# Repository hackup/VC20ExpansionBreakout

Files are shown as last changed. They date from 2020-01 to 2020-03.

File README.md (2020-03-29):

# Commodore VC20/VIC20 Cartridge Port Breakout

This is an adapter board for the [cartridge port](https://en.wikipedia.org/wiki/Commodore_VIC-20#Ports_and_sockets) of the Commodore VIC20 aka. VC20. It connects the cartridge port to a standard 830 pin prototyping breadboard to assist with the development of modules or cartridges.

Additionally, it features an optional on-board slot for either a 27c512 or 27c020 EPROM. The data bus lines D0-D7 and the address bus lines A0-A12 are connected directly to the slot, as are GND and the 5V power rail. The remaining address bus lines of the EPROM and CE/OE are available on J4. Jumper JP1 must be closed if a 27c512 chip is used.

**USE AT YOUR OWN RISK!**

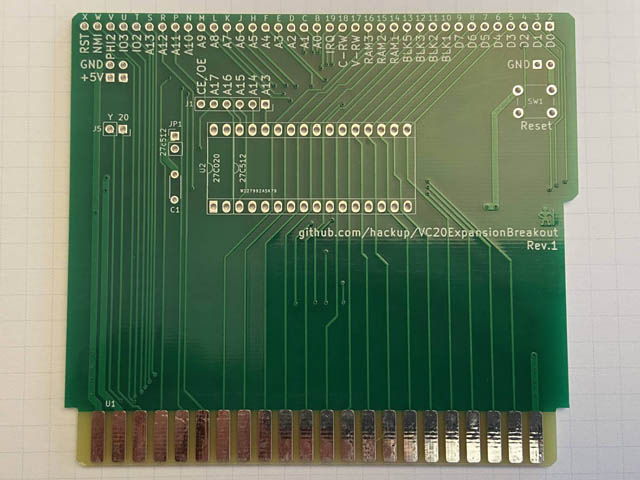
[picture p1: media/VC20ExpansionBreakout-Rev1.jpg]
VC20ExpansionBreakout Rev. 1


This adapter was modelled after my similar [breakout-board for the C64](https://github.com/hackup/C64ExpansionBreakout).

## License


This work is licensed under a
[Creative Commons Attribution-NonCommercial-ShareAlike 4.0 International License](http://creativecommons.org/licenses/by-nc-sa/4.0/).

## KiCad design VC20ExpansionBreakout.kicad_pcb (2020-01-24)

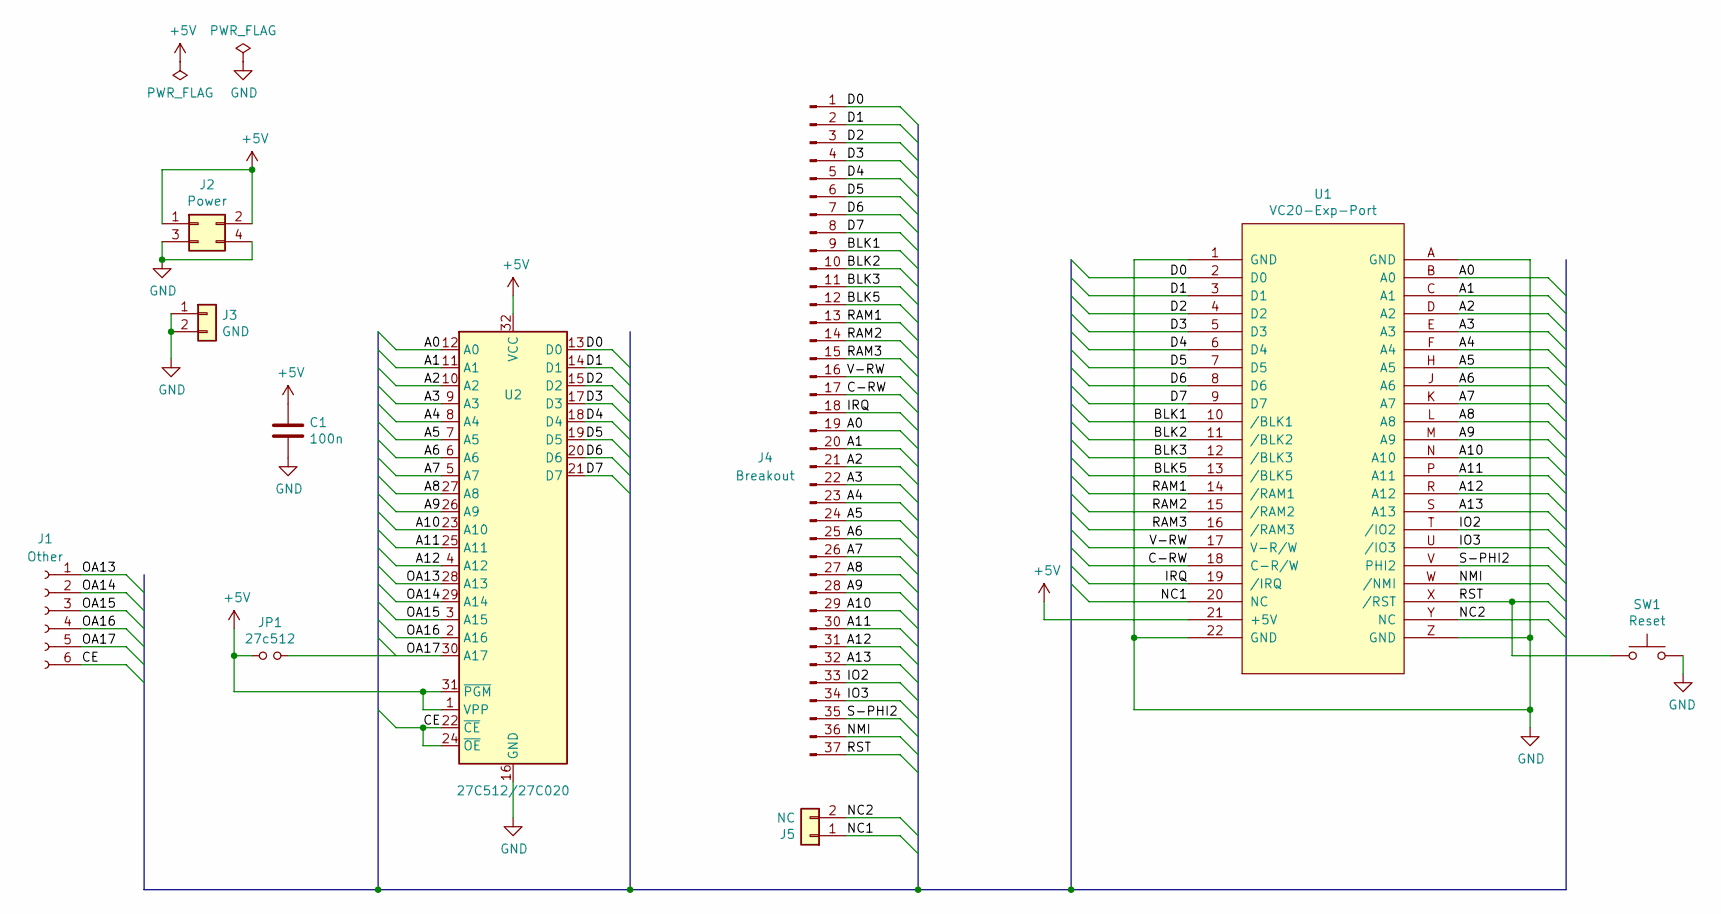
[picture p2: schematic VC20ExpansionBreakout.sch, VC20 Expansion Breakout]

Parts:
C1: 100n; C_Disc_D4.3mm_W1.9mm_P5.00mm
J1: Other; PinSocket_1x06_P2.54mm_Vertical
J2: Power; PinHeader_2x02_P2.54mm_Vertical
J3: GND; PinHeader_1x02_P2.54mm_Vertical
J4: Breakout; PinHeader_1x37_P2.54mm_Vertical
J5: NC; PinSocket_1x02_P2.54mm_Vertical
JP1: 27c512; PinHeader_1x02_P2.54mm_Vertical
SW1: Reset; SW_PUSH_6mm
U1: VC20-Exp-Port; VC20-Cart
U2: 27C512/27C020; DIP-32_W15.24mm_Socket_LongPads

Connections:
+5V: C1.1, J2.1, J2.2, JP1.1, U1.21 (+5V), U2.1 (VPP), U2.31 (~PGM), U2.32 (VCC)
/A0: J4.19, U1.B (A0), U2.12 (A0)
/A1: J4.20, U1.C (A1), U2.11 (A1)
/A2: J4.21, U1.D (A2), U2.10 (A2)
/A3: J4.22, U1.E (A3), U2.9 (A3)
/A4: J4.23, U1.F (A4), U2.8 (A4)
/A5: J4.24, U1.H (A5), U2.7 (A5)
/A6: J4.25, U1.J (A6), U2.6 (A6)
/A7: J4.26, U1.K (A7), U2.5 (A7)
/A8: J4.27, U1.L (A8), U2.27 (A8)
/A9: J4.28, U1.M (A9), U2.26 (A9)
/A10: J4.29, U1.N (A10), U2.23 (A10)
/A11: J4.30, U1.P (A11), U2.25 (A11)
/A12: J4.31, U1.R (A12), U2.4 (A12)
/A13: J4.32, U1.S (A13)
/BLK1: J4.9, U1.10 (/BLK1)
/BLK2: J4.10, U1.11 (/BLK2)
/BLK3: J4.11, U1.12 (/BLK3)
/BLK5: J4.12, U1.13 (/BLK5)
/C-RW: J4.17, U1.18 (C-R/W)
/CE: J1.6, U2.22 (~CE), U2.24 (~OE)
/D0: J4.1, U1.2 (D0), U2.13 (D0)
/D1: J4.2, U1.3 (D1), U2.14 (D1)
/D2: J4.3, U1.4 (D2), U2.15 (D2)
/D3: J4.4, U1.5 (D3), U2.17 (D3)
/D4: J4.5, U1.6 (D4), U2.18 (D4)
/D5: J4.6, U1.7 (D5), U2.19 (D5)
/D6: J4.7, U1.8 (D6), U2.20 (D6)
/D7: J4.8, U1.9 (D7), U2.21 (D7)
/IO2: J4.33, U1.T (/IO2)
/IO3: J4.34, U1.U (/IO3)
/IRQ: J4.18, U1.19 (/IRQ)
/NC1: J5.1, U1.20 (NC)
/NC2: J5.2, U1.Y (NC)
/NMI: J4.36, U1.W (/NMI)
/OA13: J1.1, U2.28 (A13)
/OA14: J1.2, U2.29 (A14)
/OA15: J1.3, U2.3 (A15)
/OA16: J1.4, U2.2 (A16)
/OA17: J1.5, JP1.2, U2.30 (A17)
/RAM1: J4.13, U1.14 (/RAM1)
/RAM2: J4.14, U1.15 (/RAM2)
/RAM3: J4.15, U1.16 (/RAM3)
/RST: J4.37, SW1.2, U1.X (/RST)
/S-PHI2: J4.35, U1.V (PHI2)
/V-RW: J4.16, U1.17 (V-R/W)
GND: C1.2, J2.3, J2.4, J3.1, J3.2, SW1.1, U1.1 (GND), U1.22 (GND), U1.A (GND), U1.Z (GND), U2.16 (GND)

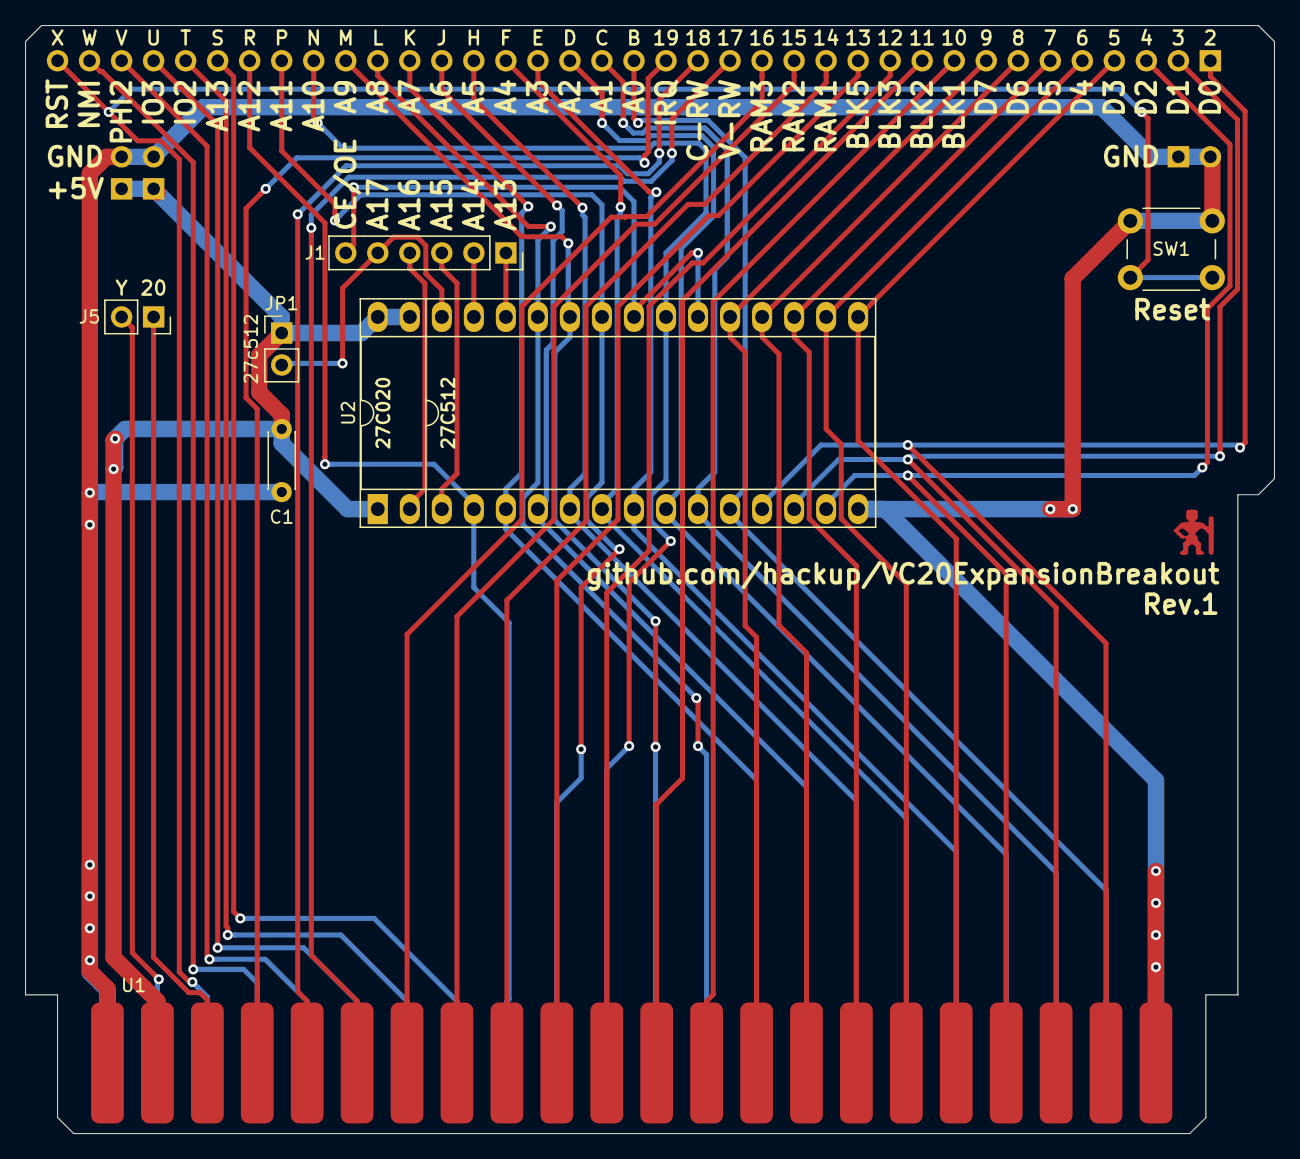
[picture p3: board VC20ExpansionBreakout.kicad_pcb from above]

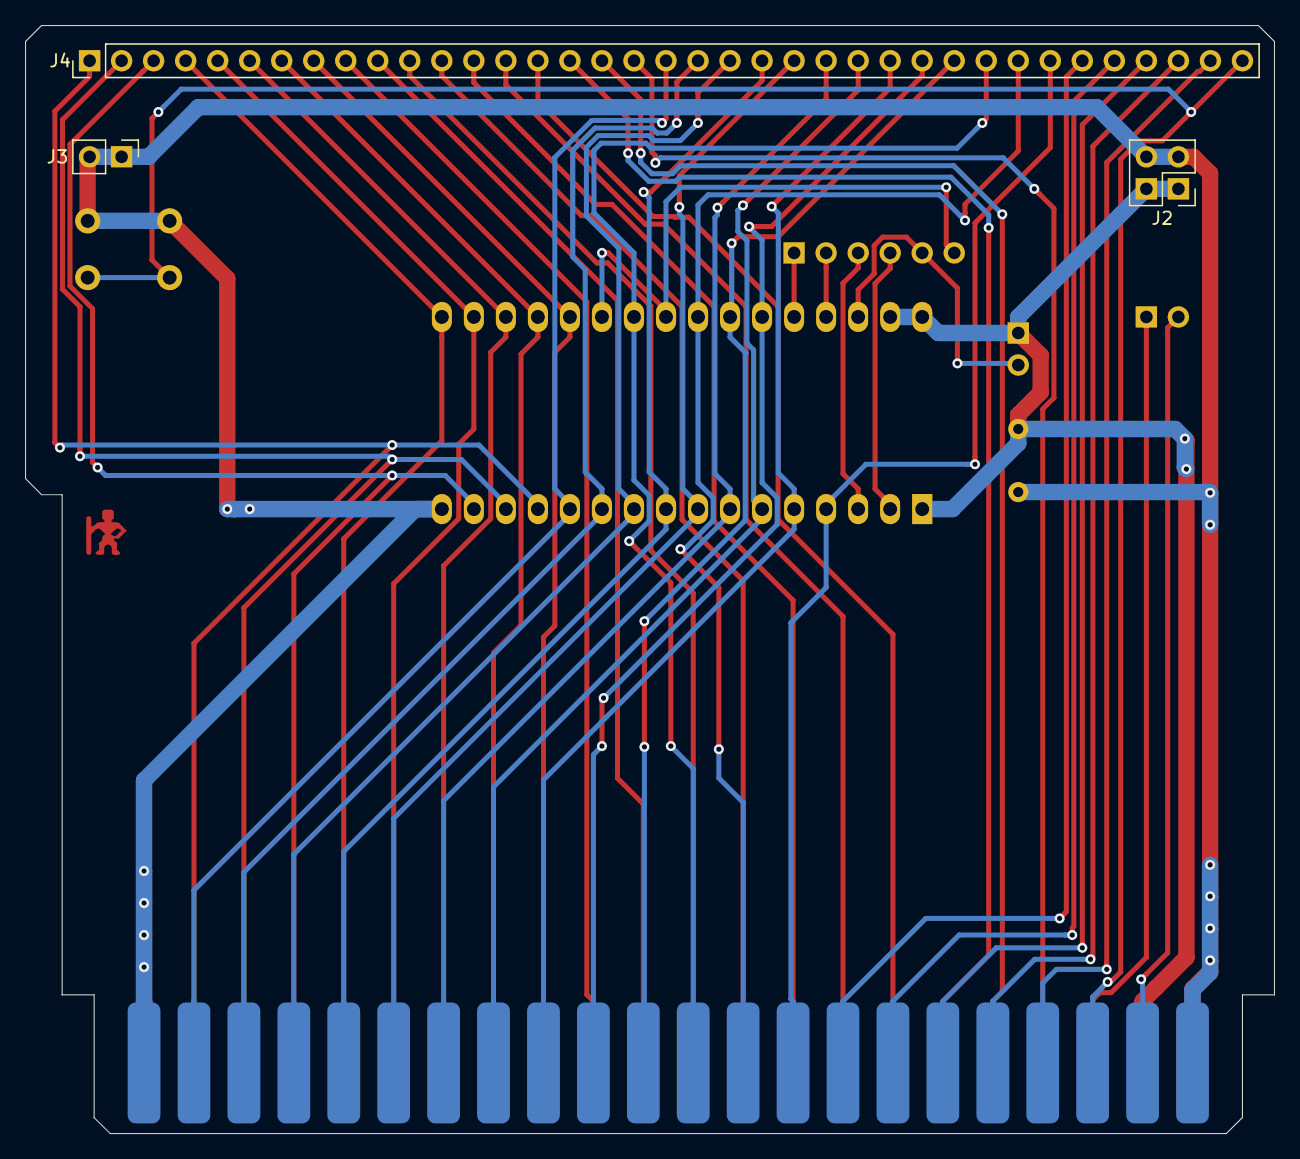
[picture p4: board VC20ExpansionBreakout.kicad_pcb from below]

Board: 2 copper layers, 99.1 x 87.9 mm, 10 parts (3 on the bottom side), 47 nets.

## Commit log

2020-01-22 Initial commit.
    [VC20ExpansionBreakout.kicad_pcb, VC20ExpansionBreakout.sch]
2020-01-22 Added missing connections.
    [VC20ExpansionBreakout.kicad_pcb, VC20ExpansionBreakout.sch]
2020-01-22 Fixing silk-screen.
    [VC20ExpansionBreakout.kicad_pcb]
2020-01-23 Fine tuning.
    [VC20ExpansionBreakout.kicad_pcb]
2020-01-24 Prepare gerber export.
    [VC20ExpansionBreakout.kicad_pcb]
